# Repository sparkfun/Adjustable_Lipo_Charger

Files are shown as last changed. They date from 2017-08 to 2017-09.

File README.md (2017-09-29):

SparkFun Adjustable LiPo Charger
============================================

Adjustable LiPo Charger

[*Adjustable LiPo Charger (PRT-14380)*](https://www.sparkfun.com/products/14380)

The Adjustable LiPo Charger will charge any single cell Lithium Ion (Li-Ion) or Lithium Polymer (LiPo) battery with a maximum current of 500mA. Simply plug in a micro B USB cable or any power supply between 3.75-6VDC to one end, and your rechargeable lithium battery to the other end. Once the current has been set on the DIP switches you're ready to go to charge your battery in 100mA increments up to 500mA, or as low as 15mA using the custom charge rate by soldering in the appropriate resistor to R_PTH.

Repository Contents
-------------------

* **/Hardware** - All Eagle design files (.brd and .sch)
* **/Production** - Production panel files

Documentation
-------------------

* [Adjustable LiPo Charger Hookup Guide ](https://learn.sparkfun.com/tutorials/adjustable-lipo-charger-hookup-guide)

License Information
-------------------
This product is _**open source**_! 

Please review the LICENSE.md file for license information. 

If you have any questions or concerns on licensing, please contact techsupport@sparkfun.com.

Distributed as-is; no warranty is given.

- Your friends at SparkFun.

All other code is open source so please feel free to do anything you want with it; you buy me a beer if you use this and we meet someday ([Beerware license](http://en.wikipedia.org/wiki/Beerware)).

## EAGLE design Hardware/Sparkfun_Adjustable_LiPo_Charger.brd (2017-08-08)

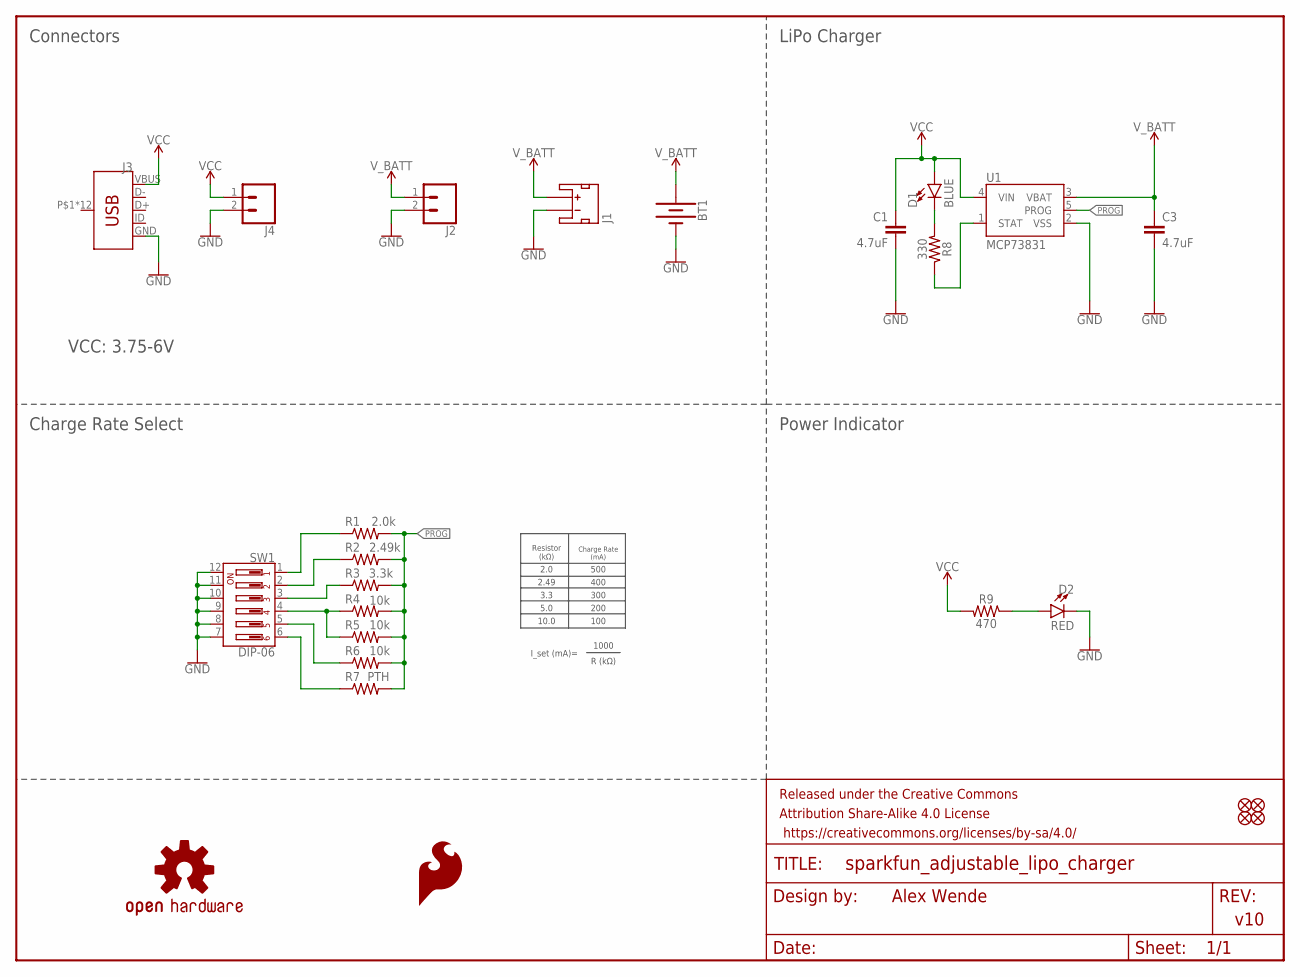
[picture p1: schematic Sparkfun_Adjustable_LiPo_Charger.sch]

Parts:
BT1: BATTERY-24.5MM_SMD; BATTCON_24.5MM_SMD
C1, C3: 4.7uF; 0603
D1: BLUE; LED-0603
D2: RED; LED-0603
FD1, FD2, FD3, FD4: FIDUCIALUFIDUCIAL; FIDUCIAL-MICRO
FRAME1: FRAME-LETTER; CREATIVE_COMMONS
J1: JST_2MM_MALE; JST-2-SMD
J2, J4: CONN_021X02_NO_SILK; 1X02_NO_SILK
J3: USB_MICRO-B_HALF_PTH; USB-MICROB-PTH
LOGO1: SFE_LOGO_FLAME.1_INCH; SFE_LOGO_FLAME_.1
LOGO2: OSHW-LOGOS; OSHW-LOGO-S
R1: 2.0k; 0603
R2: 2.49k; 0603
R3: 3.3k; 0603
R4, R5, R6: 10k; 0603
R7: PTH; AXIAL-0.3
R8: 330; 0603
R9: 470; 0603
SW1: DIP-06; DIPSWITCH-06-SMD
U1: MCP73831; SOT23-5

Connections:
GND: BT1.2 (-), C1.2, C3.2, D2.C, J1.1 (-), J2.2, J3.GND, J4.2, SW1.7, SW1.8, SW1.9, SW1.10, SW1.11, SW1.12, U1.2 (VSS)
unnamed: R8.1, U1.1 (STAT)
unnamed: R1.1, SW1.1
unnamed: R2.1, SW1.2
unnamed: R3.1, SW1.3
unnamed: R4.1, R5.1, SW1.4
unnamed: R6.1, SW1.5
unnamed: R7.P$1 (1), SW1.6
unnamed: D1.C, R8.2
unnamed: D2.A, R9.1
PROG: R1.2, R2.2, R3.2, R4.2, R5.2, R6.2, R7.P$2 (2), U1.5 (PROG)
VCC: C1.1, D1.A, J3.VBUS, J4.1, R9.2, U1.4 (VIN)
V_BATT: BT1.3 (+), C3.1, J1.2 (+), J2.1, U1.3 (VBAT)

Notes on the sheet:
Alex Wende
v10
Connectors
Charge Rate Select
Resistor (kΩ)
Charge Rate (mA)
2.0
2.49
3.3
5.0
10.0
500
400
300
200
100
I_set (mA)=
1000
R (kΩ)
LiPo Charger
VCC: 3.75-6V
Power Indicator

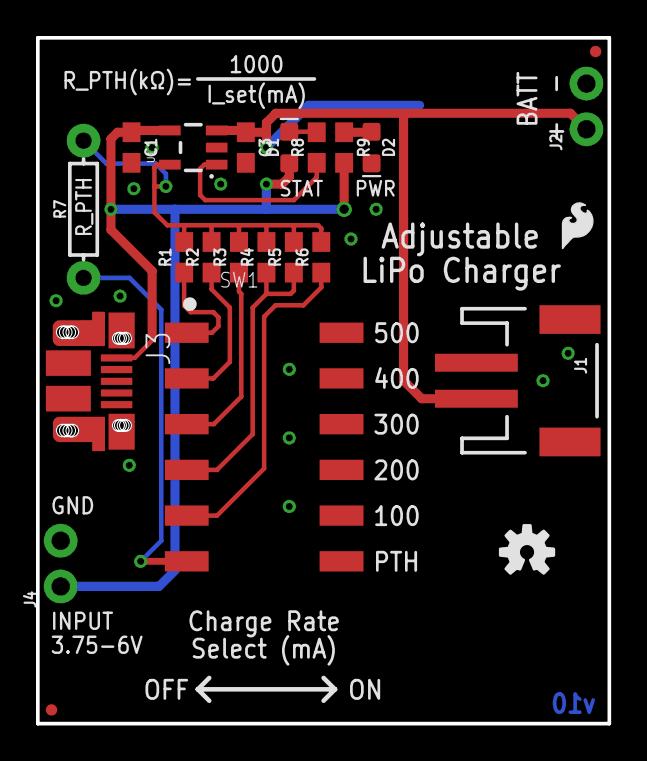
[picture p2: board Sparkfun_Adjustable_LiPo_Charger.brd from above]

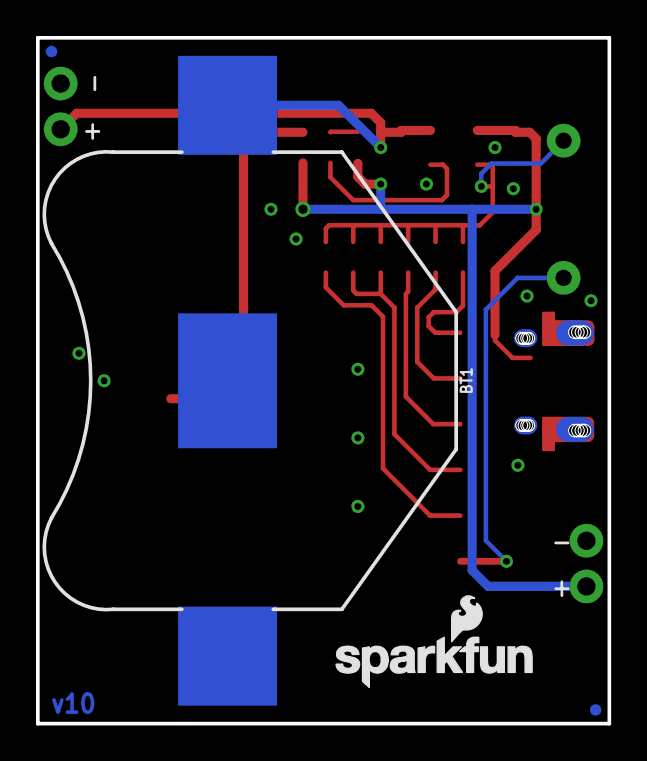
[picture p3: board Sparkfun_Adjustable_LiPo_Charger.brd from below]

Board: 2 copper layers, 31.8 x 38.1 mm, 28 parts (4 on the bottom side), 13 nets.

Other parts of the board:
U$1: SFE_LOGO_NAME_FLAME_.1

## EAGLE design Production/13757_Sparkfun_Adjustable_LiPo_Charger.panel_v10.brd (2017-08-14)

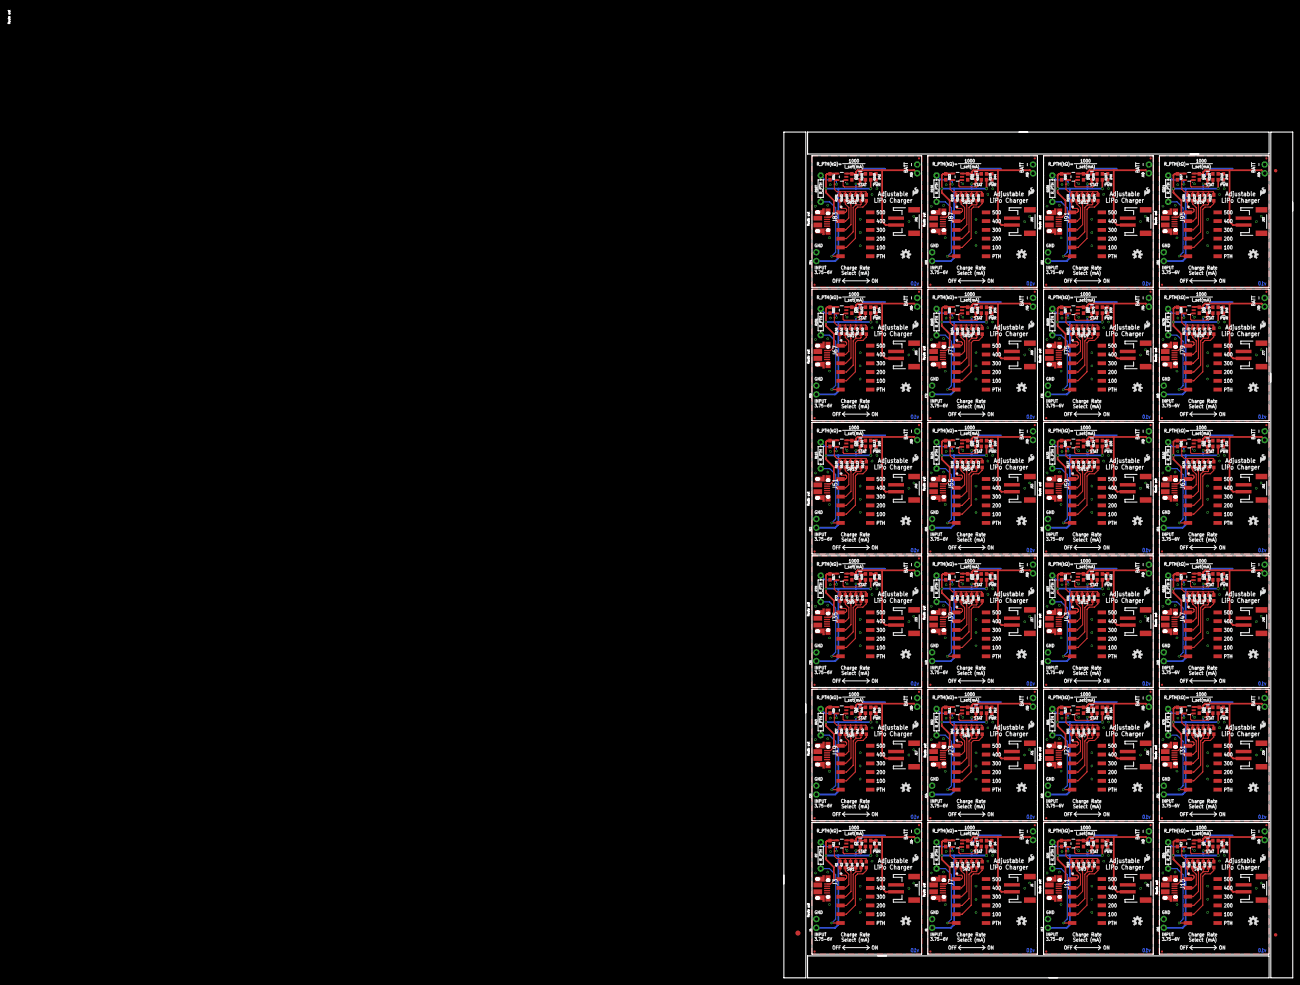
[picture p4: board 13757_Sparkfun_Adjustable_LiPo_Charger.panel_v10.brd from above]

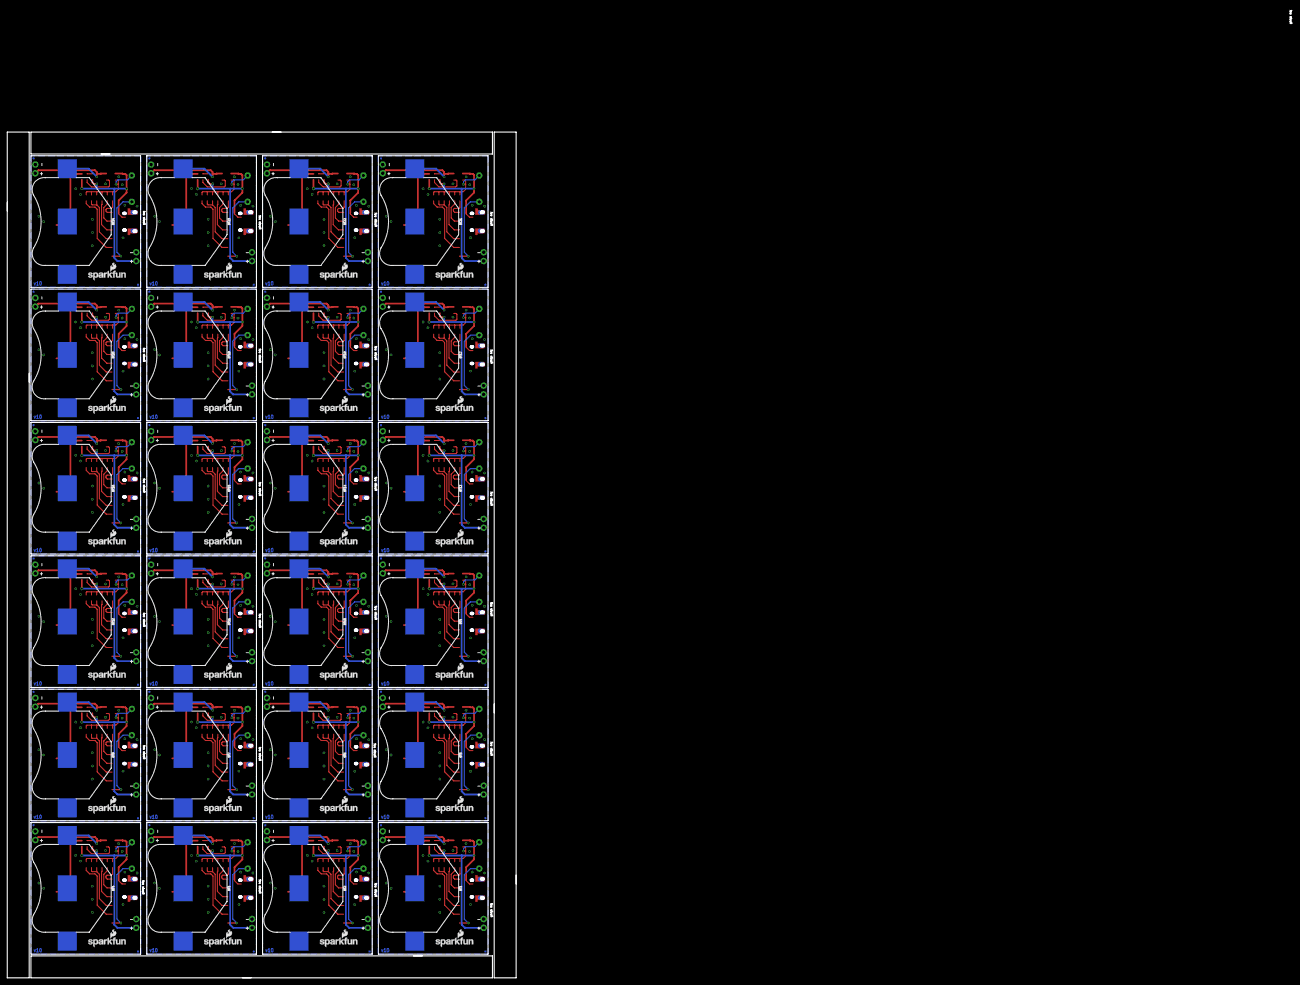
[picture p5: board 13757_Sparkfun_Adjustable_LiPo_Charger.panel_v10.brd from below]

Board: 2 copper layers, 147.3 x 244.9 mm, 651 parts (96 on the bottom side), 312 nets.

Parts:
BT1, BT2, BT3, BT4, BT5, BT6, BT7, BT8, BT9, BT10, BT11, BT12, BT13, BT14, BT15, BT16, BT17, BT18, BT19, BT20, BT21, BT22, BT23, BT24: BATTCON_24.5MM_SMD
C1, C2, C3, C4, C5, C6, C7, C8, C9, C10, C11, C12, C13, C14, C15, C16, C17, C18, C19, C20, C21, C22, C23, C24, C25, C26, C27, C28, C29, C30, C31, C32, C33, C34, C35, C36, C37, C38, C39, C40, C41, C42, C43, C44, C45, C46, C47, C48: 4.7uF; 0603
D1, D3, D5, D7, D9, D11, D13, D15, D17, D19, D21, D23, D25, D27, D29, D31, D33, D35, D37, D39, D41, D43, D45, D47: BLUE; LED-0603
D2, D4, D6, D8, D10, D12, D14, D16, D18, D20, D22, D24, D26, D28, D30, D32, D34, D36, D38, D40, D42, D44, D46, D48: RED; LED-0603
E$1: FIDUCIAL-1.5X3
E$7, E$8: FIDUCIAL-1X2
FD1, FD2, FD3, FD4, FD5, FD6, FD7, FD8, FD9, FD10, FD11, FD12, FD13, FD14, FD15, FD16, FD17, FD18, FD19, FD20, FD21, FD22, FD23, FD24, FD25, FD26, FD27, FD28, FD29, FD30, FD31, FD32, FD33, FD34, FD35, FD36, FD37, FD38, FD39, FD40, FD41, FD42, FD43, FD44, FD45, FD46, FD47, FD48, FD49, FD50, FD51, FD52, FD53, FD54, FD55, FD56, FD57, FD58, FD59, FD60, FD61, FD62, FD63, FD64, FD65, FD66, FD67, FD68, FD69, FD70, FD71, FD72, FD73, FD74, FD75, FD76, FD77, FD78, FD79, FD80, FD81, FD82, FD83, FD84, FD85, FD86, FD87, FD88, FD89, FD90, FD91, FD92, FD93, FD94, FD95, FD96: FIDUCIALUFIDUCIAL; FIDUCIAL-MICRO
J1, J5, J9, J13, J17, J21, J25, J29, J33, J37, J41, J45, J49, J53, J57, J61, J65, J69, J73, J77, J81, J85, J89, J93: JST-2-SMD
J2, J4, J6, J8, J10, J12, J14, J16, J18, J20, J22, J24, J26, J28, J30, J32, J34, J36, J38, J40, J42, J44, J46, J48, J50, J52, J54, J56, J58, J60, J62, J64, J66, J68, J70, J72, J74, J76, J78, J80, J82, J84, J86, J88, J90, J92, J94, J96: 1X02_NO_SILK
J3, J7, J11, J15, J19, J23, J27, J31, J35, J39, J43, J47, J51, J55, J59, J63, J67, J71, J75, J79, J83, J87, J91, J95: USB-MICROB-PTH
LOGO1, LOGO3, LOGO5, LOGO7, LOGO9, LOGO11, LOGO13, LOGO15, LOGO17, LOGO19, LOGO21, LOGO23, LOGO25, LOGO27, LOGO29, LOGO31, LOGO33, LOGO35, LOGO37, LOGO39, LOGO41, LOGO43, LOGO45, LOGO47: SFE_LOGO_FLAME.1_INCH; SFE_LOGO_FLAME_.1
LOGO2, LOGO4, LOGO6, LOGO8, LOGO10, LOGO12, LOGO14, LOGO16, LOGO18, LOGO20, LOGO22, LOGO24, LOGO26, LOGO28, LOGO30, LOGO32, LOGO34, LOGO36, LOGO38, LOGO40, LOGO42, LOGO44, LOGO46, LOGO48: OSHW-LOGOS; OSHW-LOGO-S
R1, R10, R19, R28, R37, R46, R55, R64, R73, R82, R91, R100, R109, R118, R127, R136, R145, R154, R163, R172, R181, R190, R199, R208: 2.0k; 0603
R2, R11, R20, R29, R38, R47, R56, R65, R74, R83, R92, R101, R110, R119, R128, R137, R146, R155, R164, R173, R182, R191, R200, R209: 2.49k; 0603
R3, R12, R21, R30, R39, R48, R57, R66, R75, R84, R93, R102, R111, R120, R129, R138, R147, R156, R165, R174, R183, R192, R201, R210: 3.3k; 0603
R4, R5, R6, R13, R14, R15, R22, R23, R24, R31, R32, R33, R40, R41, R42, R49, R50, R51, R58, R59, R60, R67, R68, R69, R76, R77, R78, R85, R86, R87, R94, R95, R96, R103, R104, R105, R112, R113, R114, R121, R122, R123, R130, R131, R132, R139, R140, R141, R148, R149, R150, R157, R158, R159, R166, R167, R168, R175, R176, R177, R184, R185, R186, R193, R194, R195, R202, R203, R204, R211, R212, R213: 10k; 0603
R7, R16, R25, R34, R43, R52, R61, R70, R79, R88, R97, R106, R115, R124, R133, R142, R151, R160, R169, R178, R187, R196, R205, R214: PTH; AXIAL-0.3
R8, R17, R26, R35, R44, R53, R62, R71, R80, R89, R98, R107, R116, R125, R134, R143, R152, R161, R170, R179, R188, R197, R206, R215: 330; 0603
R9, R18, R27, R36, R45, R54, R63, R72, R81, R90, R99, R108, R117, R126, R135, R144, R153, R162, R171, R180, R189, R198, R207, R216: 470; 0603
SW1, SW2, SW3, SW4, SW5, SW6, SW7, SW8, SW9, SW10, SW11, SW12, SW13, SW14, SW15, SW16, SW17, SW18, SW19, SW20, SW21, SW22, SW23, SW24: DIP-06; DIPSWITCH-06-SMD
U1, U2, U3, U4, U5, U6, U7, U8, U9, U10, U11, U12, U13, U14, U15, U16, U17, U18, U19, U20, U21, U22, U23, U24: MCP73831; SOT23-5
U$1, U$2, U$3, U$4, U$5, U$6, U$7, U$8, U$9, U$10, U$11, U$12, U$13, U$14, U$15, U$16, U$17, U$18, U$19, U$20, U$21, U$22, U$23, U$24: SFE_LOGO_NAME_FLAME_.1

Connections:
GND: BT1.2, C1.2, C3.2, D2.C, J1.1, J2.2, J3.GND, J4.2, SW1.7, SW1.8, SW1.9, SW1.10, SW1.11, SW1.12, U1.2
GND1: BT2.2, C2.2, C4.2, D4.C, J5.1, J6.2, J7.GND, J8.2, SW2.7, SW2.8, SW2.9, SW2.10, SW2.11, SW2.12, U2.2
GND2: BT3.2, C5.2, C6.2, D6.C, J9.1, J10.2, J11.GND, J12.2, SW3.7, SW3.8, SW3.9, SW3.10, SW3.11, SW3.12, U3.2
GND3: BT4.2, C7.2, C8.2, D8.C, J13.1, J14.2, J15.GND, J16.2, SW4.7, SW4.8, SW4.9, SW4.10, SW4.11, SW4.12, U4.2
GND4: BT5.2, C9.2, C10.2, D10.C, J17.1, J18.2, J19.GND, J20.2, SW5.7, SW5.8, SW5.9, SW5.10, SW5.11, SW5.12, U5.2
GND5: BT6.2, C11.2, C12.2, D12.C, J21.1, J22.2, J23.GND, J24.2, SW6.7, SW6.8, SW6.9, SW6.10, SW6.11, SW6.12, U6.2
GND6: BT7.2, C13.2, C14.2, D14.C, J25.1, J26.2, J27.GND, J28.2, SW7.7, SW7.8, SW7.9, SW7.10, SW7.11, SW7.12, U7.2
GND7: BT8.2, C15.2, C16.2, D16.C, J29.1, J30.2, J31.GND, J32.2, SW8.7, SW8.8, SW8.9, SW8.10, SW8.11, SW8.12, U8.2
GND8: BT9.2, C17.2, C18.2, D18.C, J33.1, J34.2, J35.GND, J36.2, SW9.7, SW9.8, SW9.9, SW9.10, SW9.11, SW9.12, U9.2
GND9: BT10.2, C19.2, C20.2, D20.C, J37.1, J38.2, J39.GND, J40.2, SW10.7, SW10.8, SW10.9, SW10.10, SW10.11, SW10.12, U10.2
GND10: BT11.2, C21.2, C22.2, D22.C, J41.1, J42.2, J43.GND, J44.2, SW11.7, SW11.8, SW11.9, SW11.10, SW11.11, SW11.12, U11.2
GND11: BT12.2, C23.2, C24.2, D24.C, J45.1, J46.2, J47.GND, J48.2, SW12.7, SW12.8, SW12.9, SW12.10, SW12.11, SW12.12, U12.2
GND12: BT13.2, C25.2, C26.2, D26.C, J49.1, J50.2, J51.GND, J52.2, SW13.7, SW13.8, SW13.9, SW13.10, SW13.11, SW13.12, U13.2
GND13: BT14.2, C27.2, C28.2, D28.C, J53.1, J54.2, J55.GND, J56.2, SW14.7, SW14.8, SW14.9, SW14.10, SW14.11, SW14.12, U14.2
GND14: BT15.2, C29.2, C30.2, D30.C, J57.1, J58.2, J59.GND, J60.2, SW15.7, SW15.8, SW15.9, SW15.10, SW15.11, SW15.12, U15.2
GND15: BT16.2, C31.2, C32.2, D32.C, J61.1, J62.2, J63.GND, J64.2, SW16.7, SW16.8, SW16.9, SW16.10, SW16.11, SW16.12, U16.2
GND16: BT17.2, C33.2, C34.2, D34.C, J65.1, J66.2, J67.GND, J68.2, SW17.7, SW17.8, SW17.9, SW17.10, SW17.11, SW17.12, U17.2
GND17: BT18.2, C35.2, C36.2, D36.C, J69.1, J70.2, J71.GND, J72.2, SW18.7, SW18.8, SW18.9, SW18.10, SW18.11, SW18.12, U18.2
GND18: BT19.2, C37.2, C38.2, D38.C, J73.1, J74.2, J75.GND, J76.2, SW19.7, SW19.8, SW19.9, SW19.10, SW19.11, SW19.12, U19.2
GND19: BT20.2, C39.2, C40.2, D40.C, J77.1, J78.2, J79.GND, J80.2, SW20.7, SW20.8, SW20.9, SW20.10, SW20.11, SW20.12, U20.2
GND20: BT21.2, C41.2, C42.2, D42.C, J81.1, J82.2, J83.GND, J84.2, SW21.7, SW21.8, SW21.9, SW21.10, SW21.11, SW21.12, U21.2
GND21: BT22.2, C43.2, C44.2, D44.C, J85.1, J86.2, J87.GND, J88.2, SW22.7, SW22.8, SW22.9, SW22.10, SW22.11, SW22.12, U22.2
GND22: BT23.2, C45.2, C46.2, D46.C, J89.1, J90.2, J91.GND, J92.2, SW23.7, SW23.8, SW23.9, SW23.10, SW23.11, SW23.12, U23.2
GND23: BT24.2, C47.2, C48.2, D48.C, J93.1, J94.2, J95.GND, J96.2, SW24.7, SW24.8, SW24.9, SW24.10, SW24.11, SW24.12, U24.2
unnamed: R8.1, U1.1
unnamed: R1.1, SW1.1
unnamed: R2.1, SW1.2
unnamed: R3.1, SW1.3
unnamed: R4.1, R5.1, SW1.4
unnamed: R6.1, SW1.5
unnamed: R7.P$1, SW1.6
unnamed: D1.C, R8.2
unnamed: R10.1, SW2.1
unnamed: R11.1, SW2.2
unnamed: R12.1, SW2.3
unnamed: D2.A, R9.1
unnamed: R13.1, R14.1, SW2.4
unnamed: R15.1, SW2.5
unnamed: R16.P$1, SW2.6
unnamed: R17.1, U2.1
unnamed: D4.A, R18.1
unnamed: D3.C, R17.2
unnamed: R19.1, SW3.1
unnamed: R20.1, SW3.2
unnamed: R21.1, SW3.3
unnamed: R22.1, R23.1, SW3.4
unnamed: R24.1, SW3.5
unnamed: R25.P$1, SW3.6
unnamed: R26.1, U3.1
unnamed: D6.A, R27.1
unnamed: D5.C, R26.2
unnamed: R28.1, SW4.1
unnamed: R29.1, SW4.2
unnamed: R30.1, SW4.3
unnamed: R31.1, R32.1, SW4.4
unnamed: R33.1, SW4.5
unnamed: R34.P$1, SW4.6
unnamed: R35.1, U4.1
unnamed: D8.A, R36.1
unnamed: D7.C, R35.2
unnamed: R37.1, SW5.1
unnamed: R38.1, SW5.2
unnamed: R39.1, SW5.3
unnamed: R40.1, R41.1, SW5.4
unnamed: R42.1, SW5.5
unnamed: R43.P$1, SW5.6
unnamed: R44.1, U5.1
unnamed: D10.A, R45.1
unnamed: D9.C, R44.2
unnamed: R46.1, SW6.1
unnamed: R47.1, SW6.2
unnamed: R48.1, SW6.3
unnamed: R49.1, R50.1, SW6.4
unnamed: R51.1, SW6.5
unnamed: R52.P$1, SW6.6
unnamed: R53.1, U6.1
unnamed: D12.A, R54.1
unnamed: D11.C, R53.2
unnamed: R55.1, SW7.1
unnamed: R56.1, SW7.2
unnamed: R57.1, SW7.3
unnamed: R58.1, R59.1, SW7.4
unnamed: R60.1, SW7.5
unnamed: R61.P$1, SW7.6
unnamed: R62.1, U7.1
unnamed: D14.A, R63.1
unnamed: D13.C, R62.2
unnamed: R64.1, SW8.1
unnamed: R65.1, SW8.2
unnamed: R66.1, SW8.3
unnamed: R67.1, R68.1, SW8.4
unnamed: R69.1, SW8.5
unnamed: R70.P$1, SW8.6
unnamed: R71.1, U8.1
unnamed: D16.A, R72.1
unnamed: D15.C, R71.2
unnamed: R73.1, SW9.1
unnamed: R74.1, SW9.2
unnamed: R75.1, SW9.3
unnamed: R76.1, R77.1, SW9.4
unnamed: R78.1, SW9.5
unnamed: R79.P$1, SW9.6
unnamed: R80.1, U9.1
unnamed: D18.A, R81.1
unnamed: D17.C, R80.2
unnamed: R82.1, SW10.1
unnamed: R83.1, SW10.2
unnamed: R84.1, SW10.3
unnamed: R85.1, R86.1, SW10.4
unnamed: R87.1, SW10.5
unnamed: R88.P$1, SW10.6
unnamed: R89.1, U10.1
unnamed: D20.A, R90.1
unnamed: D19.C, R89.2
unnamed: R91.1, SW11.1
unnamed: R92.1, SW11.2
unnamed: R93.1, SW11.3
unnamed: R94.1, R95.1, SW11.4
unnamed: R96.1, SW11.5
unnamed: R97.P$1, SW11.6
unnamed: R98.1, U11.1
unnamed: D22.A, R99.1
unnamed: D21.C, R98.2
unnamed: R100.1, SW12.1
unnamed: R101.1, SW12.2
unnamed: R102.1, SW12.3
unnamed: R103.1, R104.1, SW12.4
unnamed: R105.1, SW12.5
unnamed: R106.P$1, SW12.6
unnamed: R107.1, U12.1
unnamed: D24.A, R108.1
unnamed: D23.C, R107.2
unnamed: R109.1, SW13.1
unnamed: R110.1, SW13.2
unnamed: R111.1, SW13.3
unnamed: R112.1, R113.1, SW13.4
unnamed: R114.1, SW13.5
unnamed: R115.P$1, SW13.6
unnamed: R116.1, U13.1
unnamed: D26.A, R117.1
unnamed: D25.C, R116.2
unnamed: R118.1, SW14.1
unnamed: R119.1, SW14.2
unnamed: R120.1, SW14.3
unnamed: R121.1, R122.1, SW14.4
unnamed: R123.1, SW14.5
unnamed: R124.P$1, SW14.6
unnamed: R125.1, U14.1
unnamed: D28.A, R126.1
unnamed: D27.C, R125.2
unnamed: R127.1, SW15.1
unnamed: R128.1, SW15.2
unnamed: R129.1, SW15.3
unnamed: R130.1, R131.1, SW15.4
unnamed: R132.1, SW15.5
unnamed: R133.P$1, SW15.6
unnamed: R134.1, U15.1
unnamed: D30.A, R135.1
unnamed: D29.C, R134.2
unnamed: R136.1, SW16.1
unnamed: R137.1, SW16.2
unnamed: R138.1, SW16.3
unnamed: R139.1, R140.1, SW16.4
unnamed: R141.1, SW16.5
unnamed: R142.P$1, SW16.6
unnamed: R143.1, U16.1
unnamed: D32.A, R144.1
unnamed: D31.C, R143.2
unnamed: R145.1, SW17.1
unnamed: R146.1, SW17.2
unnamed: R147.1, SW17.3
unnamed: R148.1, R149.1, SW17.4
unnamed: R150.1, SW17.5
unnamed: R151.P$1, SW17.6
unnamed: R152.1, U17.1
unnamed: D34.A, R153.1
unnamed: D33.C, R152.2
unnamed: R154.1, SW18.1
unnamed: R155.1, SW18.2
unnamed: R156.1, SW18.3
unnamed: R157.1, R158.1, SW18.4
unnamed: R159.1, SW18.5
unnamed: R160.P$1, SW18.6
unnamed: R161.1, U18.1
unnamed: D36.A, R162.1
unnamed: D35.C, R161.2
unnamed: R163.1, SW19.1
unnamed: R164.1, SW19.2
unnamed: R165.1, SW19.3
unnamed: R166.1, R167.1, SW19.4
unnamed: R168.1, SW19.5
unnamed: R169.P$1, SW19.6
unnamed: R170.1, U19.1
unnamed: D38.A, R171.1
unnamed: D37.C, R170.2
unnamed: R172.1, SW20.1
unnamed: R173.1, SW20.2
unnamed: R174.1, SW20.3
unnamed: R175.1, R176.1, SW20.4
unnamed: R177.1, SW20.5
unnamed: R178.P$1, SW20.6
unnamed: R179.1, U20.1
unnamed: D40.A, R180.1
unnamed: D39.C, R179.2
unnamed: R181.1, SW21.1
unnamed: R182.1, SW21.2
unnamed: R183.1, SW21.3
unnamed: R184.1, R185.1, SW21.4
unnamed: R186.1, SW21.5
unnamed: R187.P$1, SW21.6
unnamed: R188.1, U21.1
unnamed: D42.A, R189.1
unnamed: D41.C, R188.2
unnamed: R190.1, SW22.1
unnamed: R191.1, SW22.2
unnamed: R192.1, SW22.3
unnamed: R193.1, R194.1, SW22.4
unnamed: R195.1, SW22.5
unnamed: R196.P$1, SW22.6
unnamed: R197.1, U22.1
unnamed: D44.A, R198.1
unnamed: D43.C, R197.2
unnamed: R199.1, SW23.1
unnamed: R200.1, SW23.2
unnamed: R201.1, SW23.3
unnamed: R202.1, R203.1, SW23.4
unnamed: R204.1, SW23.5
unnamed: R205.P$1, SW23.6
unnamed: R206.1, U23.1
unnamed: D46.A, R207.1
unnamed: D45.C, R206.2
unnamed: R208.1, SW24.1
unnamed: R209.1, SW24.2
unnamed: R210.1, SW24.3
unnamed: R211.1, R212.1, SW24.4
unnamed: R213.1, SW24.5
unnamed: R214.P$1, SW24.6
unnamed: R215.1, U24.1
unnamed: D48.A, R216.1
unnamed: D47.C, R215.2
PROG: R1.2, R2.2, R3.2, R4.2, R5.2, R6.2, R7.P$2, U1.5
PROG1: R10.2, R11.2, R12.2, R13.2, R14.2, R15.2, R16.P$2, U2.5
PROG2: R19.2, R20.2, R21.2, R22.2, R23.2, R24.2, R25.P$2, U3.5
PROG3: R28.2, R29.2, R30.2, R31.2, R32.2, R33.2, R34.P$2, U4.5
PROG4: R37.2, R38.2, R39.2, R40.2, R41.2, R42.2, R43.P$2, U5.5
PROG5: R46.2, R47.2, R48.2, R49.2, R50.2, R51.2, R52.P$2, U6.5
PROG6: R55.2, R56.2, R57.2, R58.2, R59.2, R60.2, R61.P$2, U7.5
PROG7: R64.2, R65.2, R66.2, R67.2, R68.2, R69.2, R70.P$2, U8.5
PROG8: R73.2, R74.2, R75.2, R76.2, R77.2, R78.2, R79.P$2, U9.5
PROG9: R82.2, R83.2, R84.2, R85.2, R86.2, R87.2, R88.P$2, U10.5
PROG10: R91.2, R92.2, R93.2, R94.2, R95.2, R96.2, R97.P$2, U11.5
PROG11: R100.2, R101.2, R102.2, R103.2, R104.2, R105.2, R106.P$2, U12.5
PROG12: R109.2, R110.2, R111.2, R112.2, R113.2, R114.2, R115.P$2, U13.5
PROG13: R118.2, R119.2, R120.2, R121.2, R122.2, R123.2, R124.P$2, U14.5
PROG14: R127.2, R128.2, R129.2, R130.2, R131.2, R132.2, R133.P$2, U15.5
PROG15: R136.2, R137.2, R138.2, R139.2, R140.2, R141.2, R142.P$2, U16.5
PROG16: R145.2, R146.2, R147.2, R148.2, R149.2, R150.2, R151.P$2, U17.5
PROG17: R154.2, R155.2, R156.2, R157.2, R158.2, R159.2, R160.P$2, U18.5
PROG18: R163.2, R164.2, R165.2, R166.2, R167.2, R168.2, R169.P$2, U19.5
PROG19: R172.2, R173.2, R174.2, R175.2, R176.2, R177.2, R178.P$2, U20.5
PROG20: R181.2, R182.2, R183.2, R184.2, R185.2, R186.2, R187.P$2, U21.5
PROG21: R190.2, R191.2, R192.2, R193.2, R194.2, R195.2, R196.P$2, U22.5
PROG22: R199.2, R200.2, R201.2, R202.2, R203.2, R204.2, R205.P$2, U23.5
PROG23: R208.2, R209.2, R210.2, R211.2, R212.2, R213.2, R214.P$2, U24.5
VCC: C1.1, D1.A, J3.VBUS, J4.1, R9.2, U1.4
VCC1: C2.1, D3.A, J7.VBUS, J8.1, R18.2, U2.4
VCC2: C5.1, D5.A, J11.VBUS, J12.1, R27.2, U3.4
VCC3: C7.1, D7.A, J15.VBUS, J16.1, R36.2, U4.4
VCC4: C9.1, D9.A, J19.VBUS, J20.1, R45.2, U5.4
VCC5: C11.1, D11.A, J23.VBUS, J24.1, R54.2, U6.4
VCC6: C13.1, D13.A, J27.VBUS, J28.1, R63.2, U7.4
VCC7: C15.1, D15.A, J31.VBUS, J32.1, R72.2, U8.4
VCC8: C17.1, D17.A, J35.VBUS, J36.1, R81.2, U9.4
VCC9: C19.1, D19.A, J39.VBUS, J40.1, R90.2, U10.4
VCC10: C21.1, D21.A, J43.VBUS, J44.1, R99.2, U11.4
VCC11: C23.1, D23.A, J47.VBUS, J48.1, R108.2, U12.4
VCC12: C25.1, D25.A, J51.VBUS, J52.1, R117.2, U13.4
VCC13: C27.1, D27.A, J55.VBUS, J56.1, R126.2, U14.4
VCC14: C29.1, D29.A, J59.VBUS, J60.1, R135.2, U15.4
VCC15: C31.1, D31.A, J63.VBUS, J64.1, R144.2, U16.4
VCC16: C33.1, D33.A, J67.VBUS, J68.1, R153.2, U17.4
VCC17: C35.1, D35.A, J71.VBUS, J72.1, R162.2, U18.4
VCC18: C37.1, D37.A, J75.VBUS, J76.1, R171.2, U19.4
VCC19: C39.1, D39.A, J79.VBUS, J80.1, R180.2, U20.4
VCC20: C41.1, D41.A, J83.VBUS, J84.1, R189.2, U21.4
VCC21: C43.1, D43.A, J87.VBUS, J88.1, R198.2, U22.4
VCC22: C45.1, D45.A, J91.VBUS, J92.1, R207.2, U23.4
VCC23: C47.1, D47.A, J95.VBUS, J96.1, R216.2, U24.4
V_BATT: BT1.3, C3.1, J1.2, J2.1, U1.3
V_BATT1: BT2.3, C4.1, J5.2, J6.1, U2.3
V_BATT2: BT3.3, C6.1, J9.2, J10.1, U3.3
V_BATT3: BT4.3, C8.1, J13.2, J14.1, U4.3
V_BATT4: BT5.3, C10.1, J17.2, J18.1, U5.3
V_BATT5: BT6.3, C12.1, J21.2, J22.1, U6.3
V_BATT6: BT7.3, C14.1, J25.2, J26.1, U7.3
V_BATT7: BT8.3, C16.1, J29.2, J30.1, U8.3
V_BATT8: BT9.3, C18.1, J33.2, J34.1, U9.3
V_BATT9: BT10.3, C20.1, J37.2, J38.1, U10.3
V_BATT10: BT11.3, C22.1, J41.2, J42.1, U11.3
V_BATT11: BT12.3, C24.1, J45.2, J46.1, U12.3
V_BATT12: BT13.3, C26.1, J49.2, J50.1, U13.3
V_BATT13: BT14.3, C28.1, J53.2, J54.1, U14.3
V_BATT14: BT15.3, C30.1, J57.2, J58.1, U15.3
V_BATT15: BT16.3, C32.1, J61.2, J62.1, U16.3
V_BATT16: BT17.3, C34.1, J65.2, J66.1, U17.3
V_BATT17: BT18.3, C36.1, J69.2, J70.1, U18.3
V_BATT18: BT19.3, C38.1, J73.2, J74.1, U19.3
V_BATT19: BT20.3, C40.1, J77.2, J78.1, U20.3
V_BATT20: BT21.3, C42.1, J81.2, J82.1, U21.3
V_BATT21: BT22.3, C44.1, J85.2, J86.1, U22.3
V_BATT22: BT23.3, C46.1, J89.2, J90.1, U23.3
V_BATT23: BT24.3, C48.1, J93.2, J94.1, U24.3

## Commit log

2017-06-28 Added hardware
    Added the schematic and board files
    [Sparkfun_Adjustable_LiPo_Charger.brd, Sparkfun_Adjustable_LiPo_Charger.sch]
2017-06-30 Design Review Changes
    Replaced PTH coin cell holder with SMD
    [Sparkfun_Adjustable_LiPo_Charger.brd, Sparkfun_Adjustable_LiPo_Charger.sch]
2017-08-04 Proto Changes
    Fixed layout error of D1 to the correct orientation
    [Sparkfun_Adjustable_LiPo_Charger.brd, Sparkfun_Adjustable_LiPo_Charger.sch]
2017-08-08 v10 changes
    - Added switch label to indicate on/off position.
    - Added units to charge rate equation
    [Sparkfun_Adjustable_LiPo_Charger.brd, Sparkfun_Adjustable_LiPo_Charger.sch]

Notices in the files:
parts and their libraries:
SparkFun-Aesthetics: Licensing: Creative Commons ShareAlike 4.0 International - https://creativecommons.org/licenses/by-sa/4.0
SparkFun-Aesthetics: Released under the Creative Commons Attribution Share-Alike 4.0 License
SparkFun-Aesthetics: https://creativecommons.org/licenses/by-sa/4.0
